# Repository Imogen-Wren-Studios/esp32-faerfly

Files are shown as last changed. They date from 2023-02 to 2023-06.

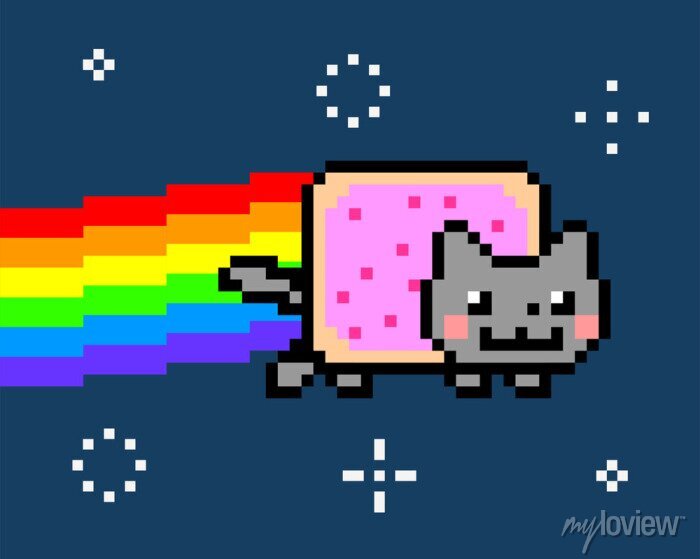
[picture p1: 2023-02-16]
image-sources/space-cat-creating-rainbo.jpg

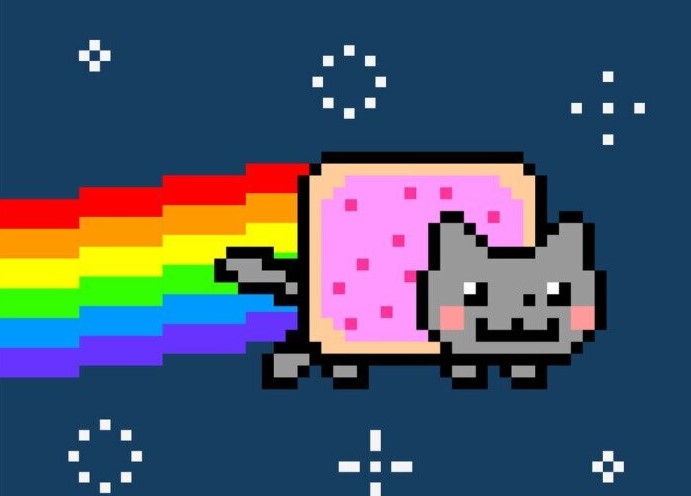
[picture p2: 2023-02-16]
image-sources/space-cat-creating-rainbow-crop.jpg

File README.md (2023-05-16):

#ESP32 FaerFly - Development Board
 Imogen Wren Business Card PCB
 





## Project Outline

_The project is a business card that can be handed out at gigs and work, and also a fun project to build!_

### Requirements
 1. A PCB business card I can hand out to people at gigs / work to advertise myself
 2. A fun electronics project or thing

### Idea

1. Mini pocket lightshow. Rechargable and interactive. Probably get it fabbed so it isnt a soldering project, but include a programming port so it can be reprogrammed easily. <br>
     **Advantages:**
    - Fun programming challenge - Can link to repo with working code in case of bricking
    - Card more likely to be used in the open and interacted with over time
    - Would have to be handed out with everything attached
    - Could exclude battery and make a point of indicating to reuse broken disposible vape for battery. Recycling electronic waste! 

 ## Strech Features
 
 - NFC Tap phone to link to linktree?
 - Edge connectors could be used as both touch interface, and connection to other hardware. Generic port? Is this now a new form we are trying to invent for development boards?
 - 3d printed case for different functions, like exposed touch pins, 

 ## Circuit Snippets
 
 ### WS2821b LED Implementation
 
  <br>
https://cdn-shop.adafruit.com/datasheets/WS2812B.pdf
- Vdd = 3.5 - 5.6 
- Vinput = VDD +-0.5

 Battery can be unregulated direct to LEDs & regulated to microcontroller
Slot for 2nd regulator for powering with 2s? or KISS

I think KISS

### Charging IC and LOw Voltage Cutoff

https://www.mouser.co.uk/ProductDetail/Littelfuse/SMAJ350A?

## Research

### AtTiny85 Interface
**DrAzzy - ATtiny Obsessee**
_Jan '20post #2_
_If you use my core (board manager url in sig), there is a serial bootloader (use the (optiboot) board def).
But you will still need an ISP programmer or arduino running Arduino as ISP sketch to bootload it (usbasps and nano clones are both 3 bucks or so on ebay/aliexpress, either is suitable).
You will also need a 0.1uf cap and 10k resistor for the autoreset circuit so the serial adapter can reset it into the bootloader. (Also, dont forget that you also need a 0.1uf ceramic cap between power and ground close to the t85 ti ensure reliable operation; without this the chip may behave erratically depending on circumstances - I mention this because it is very often omitted in designs I see here, particularly with tinies. You always need this for digital ICs unless otherwise specified in the datasheet. With the t85, if on breadboard or protoboard, i usually put this across the top of the chip to minimize the distance between cap and chip)_

#### USB - SPI Bridge

https://www.mouser.co.uk/ProductDetail/Microchip-Technology/MIC2550AYTS

#### USB C Connectors
https://www.mouser.co.uk/ProductDetail/Amphenol-Commercial-Products/124018402112A
https://www.lcsc.com/product-detail/span-style-background-color-ff0-USB-span-Connectors_G-Switch-GT-USB-7007A_C5299422.html

### LiPo Battery Charging
#### 1S
https://uk.rs-online.com/web/p/battery-management/7386360
https://www.mouser.co.uk/ProductDetail/Microchip-Technology-Atmel/MCP73832T-5ACI-OT
https://www.mouser.co.uk/datasheet/2/268/20001984g-846362.pdf

#### 2S
https://www.mouser.co.uk/ProductDetail/Microchip-Technology/MCP73844T-820I-MS

_This option needs regulator to 5v_

### Microcontroller Options
#### AtTiny85
- https://uk.farnell.com/microchip/attiny85-20su/mcu-8bit-attiny-20mhz-wsoic-8/dp/1455164
- Feels more "Haxxor" using a tiny processor
- More Difficult to implement
- The device achieves a throughput of 20 MIPS at 20 MHz and operates between 2.7 to 5.5V.
   - In voltage range 
- Have code almost ready to run https://github.com/Imogen-Wren-Studios/unicorn-attiny85

#### SAMD21
- 3.3v  MUST BE REGULATED
- Lots of experience with device
- https://www.mouser.co.uk/ProductDetail/Microchip-Technology/ATSAMD21E16L-AF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

#### AtMega382p
- Most commonly understood platform - better engagement
- https://www.lcsc.com/product-detail/Microcontroller-Units-MCUs-MPUs-SOCs_Microchip-Tech-ATMEGA328P-AU_C14877.html
- Expensive
- in stock ATM
- 1.8 - 5.5v - No Need for Regulator
  - Qty.	Unit Price	Ext. Price
  - 1+	US  $3.045
  - 10+	US  $2.7126 - 	US$ 27.13

### ESP32
- 3v3 Only - needs regulating
- Wifiability gives further haxxor abilities
- OTA Updates
https://www.lcsc.com/product-detail/WiFi-Modules_Espressif-Systems-ESP32-WROOM-32-N4_C82899.html
- Have some code that could be used: https://github.com/Imogen-Wren-Studios/esp32-ws2812b-glediator
- Price: 
  - 1+   -  	US$3.2455	
  - 10+	 -   US$2.9273

### Capaciative Sensing

https://www.instructables.com/Capacitive-Sensing-for-Dummies/
_Seems to mostly be used with a microcontroller, havnt managed to find an analog audio implementation yet_

https://docs.arduino.cc/built-in-examples/analog/Smoothing Smoothing Data from Capacative touch sensor

## Continued Development

Now the project has become more clearly defined, it is an ESP development board with built in WS2821b LEDs designed to be used as a wearable badge, or a light up stand
for 3D printing projects. It contains mounting tabs to assit in adding diffusers and optics. The wifi can be used to coordinate groups of them to sync colours around the room.

## Version 2 Development

After using version 1 for a little time, some clear places to improve have materialised.

1.  [] Replace GPIO surface pins with through holes
2.  [] Replace USB to serial with CP2102, CH340 is too flakey see [CP2102 USB to UART](https://blackcatsoftware.us/wp-content/uploads/2020/06/esp32-devkit-v1-schematic.pdf)
3.  [] Add BMP280 temp sensor
4.  [] Add Accellerometer
5.  [] Add digital microphone? - test theory before committing
6.  [] DMX interface? -> `The DMX output required the use of a MAX485 transceiver connected to the TX-pin of the ESP in order to produce DMX output.` `If you need to use another pin for output than the TX-pin, you'll need to change this in the ESP-Dmx library itself. This setting is located in src/dependencies/dmx/ESPDMX.cpp on line 31.`
7.  [x] Battery Positive to ADC1 (GPIO32-39) with 100k resistor for battery usermod
8.  [x] Change Battery Switch to switch between USB and battery (why didnt do this on version 1?!?!)
9.  [x] Check max charge current for BMS. Need at least 1A if possible 550mA max using 2k ohm shunt resistor

Does DMX make this project something it is not?

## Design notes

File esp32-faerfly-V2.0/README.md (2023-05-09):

# ESP32 - FaerFly - Version 2.0

## Changelog

- Added 100n cap from EN to GND for auto reset

## TODO

- Add Acellerometer
- Add BMP280 Sensors
- Change touch pins to holes, touch pins DID NOT work well

## Strech Goals

- Cut PCB size down to just the LEDs footprint - Use front and back of PCB

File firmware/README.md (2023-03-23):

# ESP32 FaerFly - Firmware README

## Concept and Initial Ideas

The brief is to design a light show, with wireless communication between devices to sync colours and patterns.

## Operational Modes
_More can be added as time goes on_

1. Known Starting Position into Randomness

Lightshow starts from a given frame, and then over time random elements are added. This will be easy to coordinate wirelessly, as the _leader_ simply has to 
transmit a starting point for the lightshow, then over t(time) the follower units can add their own random elements. This will look striking as elements will
seem to sync up then drift apart over time. The dataframe could contain the following information:

1. Colour 1*
2. Colour 2
3. Colour 3
4. Colour 4
5. Movement Pattern(s)
6. transition time (i.e. transition time set to 0 would update all followers instantly, wheres setting a transition of a few seconds to minuites would create the effect of the elements slowly drifting together and apart again.
7. brightness
8. time t to start introducing random elements
9. accelleration, how quickly to ramp up random elements

*Note colours could themselves be predefined pallets containing several colours

The advantage of this topology is all of these parameters can be coded into the leader for testing, and then would need just 1 dataframe between leader and followers to act.

## Development Map

1. Develop the single lightshow for the leader, using basic colours, movement and brightness
2. Introduce random elements over time
3. Change the speed of changes of random elements (accelleration)
4. introduce delay before adding random elements
5. Start development of wireless dataframe transmission
6. Start development of wireless dataframe reception
7. add additional animation elements, movements, fades & pulses
8. Add support for palettes as well as single colours.

- At this point this operational mode should be complete.

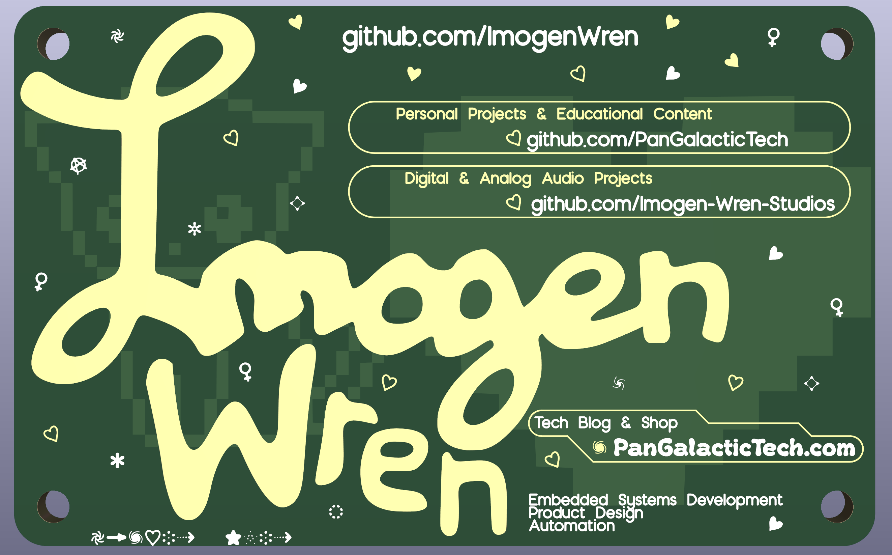
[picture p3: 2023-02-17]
Renders/Version 1 Render.png

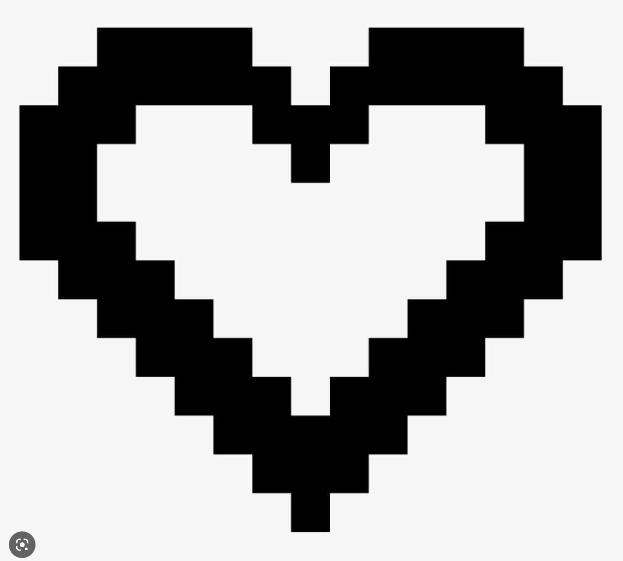
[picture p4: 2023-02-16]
image-sources/8-bit-heart-one.jpg

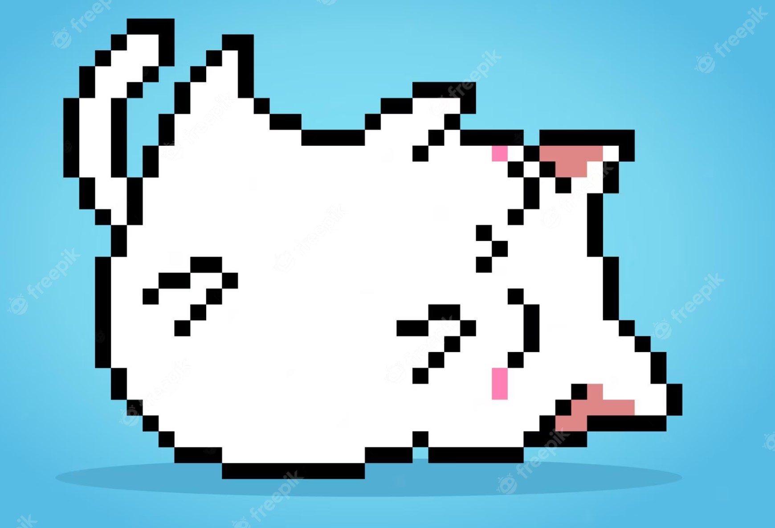
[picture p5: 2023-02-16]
image-sources/cat-rolling-back.jpg

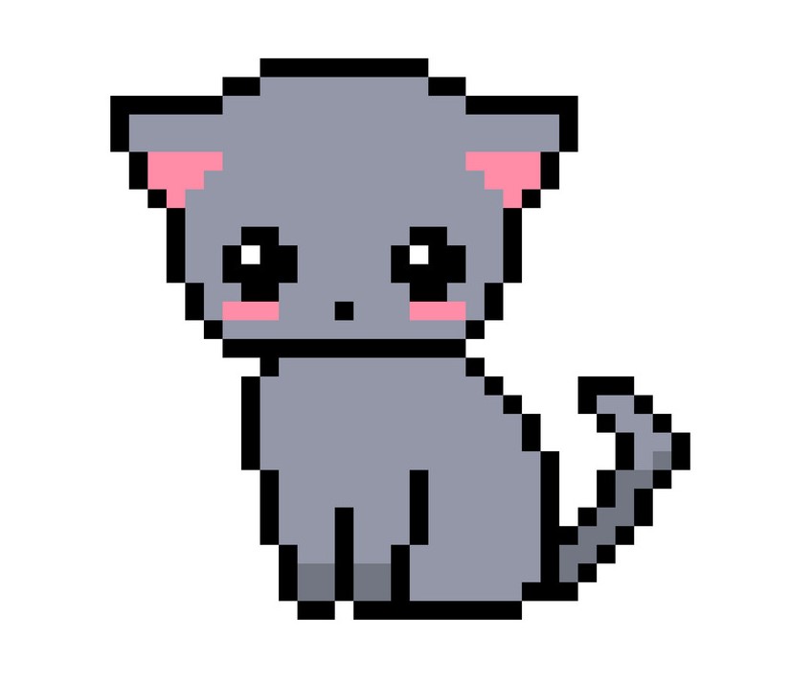
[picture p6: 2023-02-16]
image-sources/8-bit-pixel-gray-cat-cartoon-vector.jpg

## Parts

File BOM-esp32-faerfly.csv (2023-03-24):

# | Reference | Qty | Value | Footprint | DNP | JLCpart | Cost
1 | C1, C2, C3, C4, C5, C6, C7, C10, C13, C14, C15, C16, C17, C18, C19, C20, C21, C22, C23, C24 | 20 | 100n | 000_Capacitors_Immo:C_0805_2012_HandSolder_kawaii |  | C779975 | 0.02
2 | C8 | 1 | 10n | 000_Capacitors_Immo:C_0805_2012_HandSolder_kawaii |  | C83170 | 0.0051
3 | C9, C11 | 2 | 47p | 000_Capacitors_Immo:C_0805_2012_HandSolder_kawaii |  | C24659 | 0.0056
4 | C12 | 1 | 4n7 | 000_Capacitors_Immo:C_0805_2012_HandSolder_kawaii |  | C2915753 | 0.0118
5 | C25, C26 | 2 | 4u7 | Capacitor_Tantalum_SMD:CP_EIA-2012-12_Kemet-R_Pad1.30x1.05mm_HandSolder |  | C1954175 | 0.0994
6 | D1 | 1 | Blue | Diode_SMD:D_0805_2012Metric_Pad1.15x1.40mm_HandSolder |  | C84261 | 0.0158
7 | D2, D3 | 2 | BZV55B3V3 | Diode_SMD:D_MiniMELF |  | C268735 | 0.0221
8 | EC1 | 1 | 1000u | Capacitor_SMD:CP_Elec_10x10 |  | C134726 | 0.1866
9 | FB1 | 1 | FerriteBead | Inductor_SMD:L_0805_2012Metric_Pad1.05x1.20mm_HandSolder |  | C845115 | 0.558
10 | J8 | 1 | USB_C_Receptacle | Connector_USB:USB_C_Receptacle_Molex_105450-0101 |  | C134092 | 0.6619
12 | Q1, Q2 | 2 | BC817 | Package_TO_SOT_SMD:SOT-23 |  | C2137 | 0.0225
13 | R1, R2, R8, R9, R10, R11 | 6 | 10k | Resistor_SMD:R_0805_2012Metric_Pad1.20x1.40mm_HandSolder |  | C2930231 | 0.002
14 | R3, R12 | 2 | 4k7 | Resistor_SMD:R_0805_2012Metric_Pad1.20x1.40mm_HandSolder |  | C5140142 | 0.002
15 | R4, R5 | 2 | 27r | Resistor_SMD:R_0805_2012Metric_Pad1.20x1.40mm_HandSolder |  | C779975 | 0.002
16 | R6 | 1 | 470r | Resistor_SMD:R_0805_2012Metric_Pad1.20x1.40mm_HandSolder |  | C280020 | 0.0027
17 | R7 | 1 | 330r | Resistor_SMD:R_0805_2012Metric_Pad1.20x1.40mm_HandSolder |  | C3017834 | 0.0016
18 | R13, R14, R17 | 3 | 1k | Resistor_SMD:R_0805_2012Metric_Pad1.20x1.40mm_HandSolder |  | C218388 | 0.0082
19 | R15, R16 | 2 | 100r | Resistor_SMD:R_0805_2012Metric_Pad1.20x1.40mm_HandSolder |  | C217766 | 0.0093
20 | SW1 | 1 | SW_SPDT_small | 000_Switches_Immo:SW_SPDT_PCM12 |  | C221841 | 0.4487
21 | SW2 | 1 | BOOT | 000_Switches_Immo:SW_SPST_EVQPE1 |  | C699451 | 0.3052
22 | SW3 | 1 | EN | 000_Switches_Immo:SW_SPST_EVQPE1 |  | C699451 | 0.3052
23 | U1 | 1 | MCP73831-2-OT | Package_TO_SOT_SMD:SOT-23-5 |  | C424093 | 0.778
24 | U2 | 1 | AMS1117-3.3 | Package_TO_SOT_SMD:SOT-223-3_TabPin2 |  | C2992570 | 0.0488
25 | U3 | 1 | ESP32-WROOM-32 | RF_Module:ESP32-WROOM-32 |  | C473012 - C529577 | 3.5016
26 | U4 | 1 | CH340C | Package_SO:SOIC-16_3.9x9.9mm_P1.27mm |  | C84681 | 0.4725
27 | WLED1, WLED2, WLED3, WLED4, WLED5, WLED6, WLED7, WLED8, WLED9, WLED10, WLED11, WLED12 | 12 | WS2812B | LED_SMD:LED_WS2812B_PLCC4_5.0x5.0mm_P3.2mm |  | C2920042 | 0.0768

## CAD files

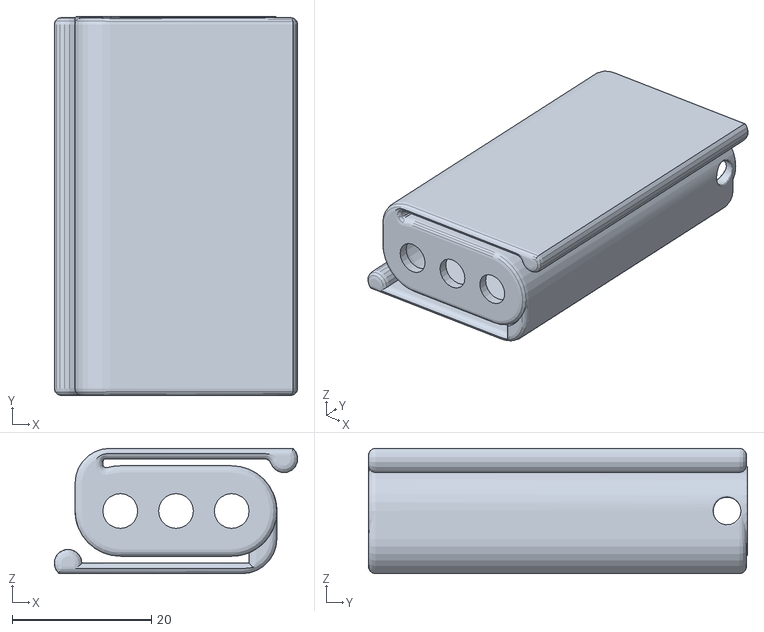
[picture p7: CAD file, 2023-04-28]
3D-cad/esp32-faerfly-inventor/case-stls/battery-holder/v2.0-B-battery-holder.stl
35.0 x 54.4 x 18.0

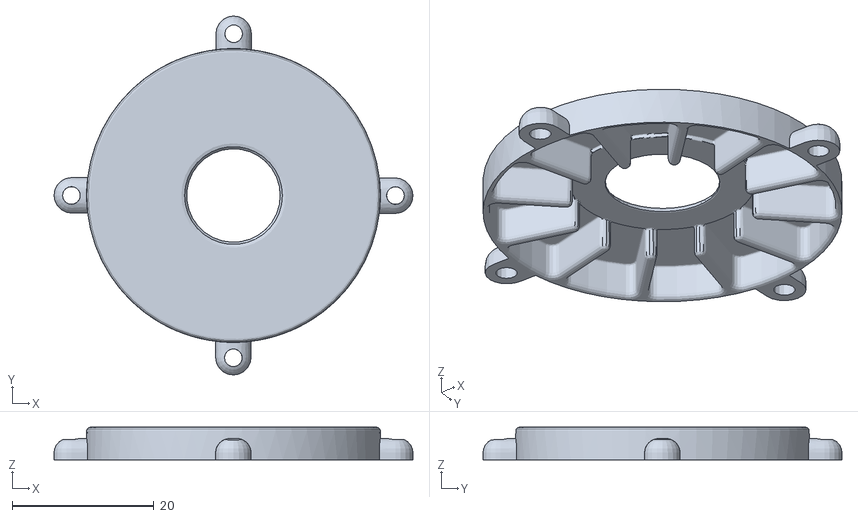
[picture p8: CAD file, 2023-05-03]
3D-cad/esp32-faerfly-inventor/case-stls/FINAL_VERSIONS/V3.0-diffuser_versionB.stl
50.6 x 50.6 x 4.60

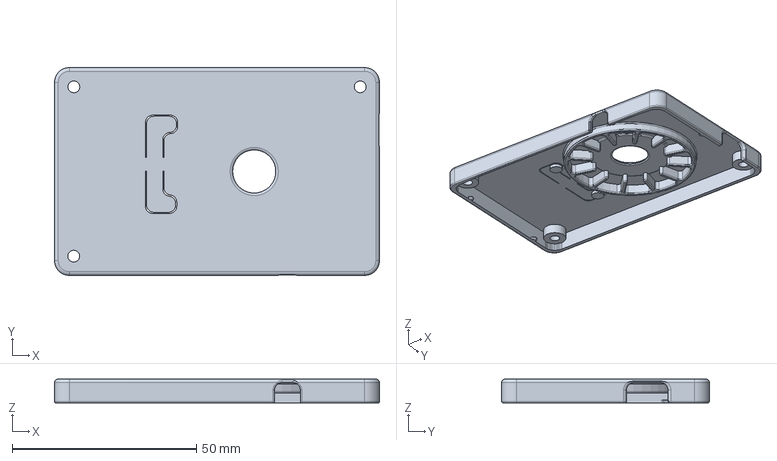
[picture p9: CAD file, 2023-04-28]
3D-cad/esp32-faerfly-inventor/case-topsideV1.3_A.stp
88.1 x 56.3 x 6.50 mm

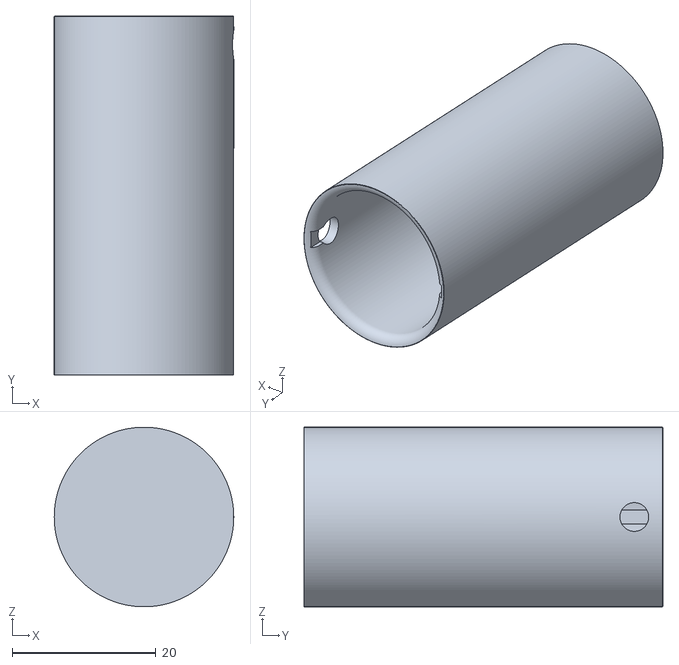
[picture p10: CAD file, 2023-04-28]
3D-cad/esp32-faerfly-inventor/case-stls/battery-holder/V1.0-battery-holder-A.stl
25.0 x 50.0 x 25.0

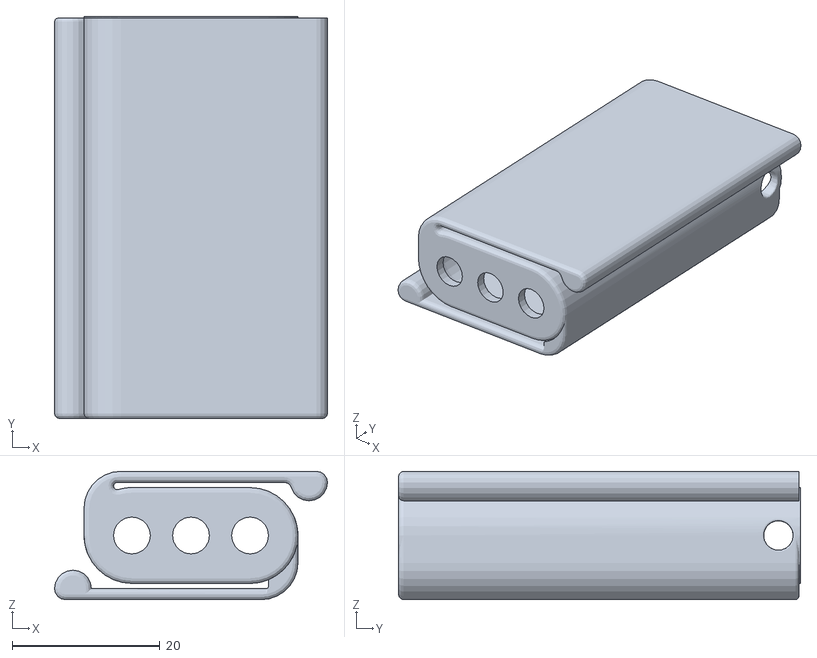
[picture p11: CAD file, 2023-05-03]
3D-cad/esp32-faerfly-inventor/case-stls/FINAL_VERSIONS/v2.0-B-battery-holder.stl
37.0 x 54.5 x 17.4

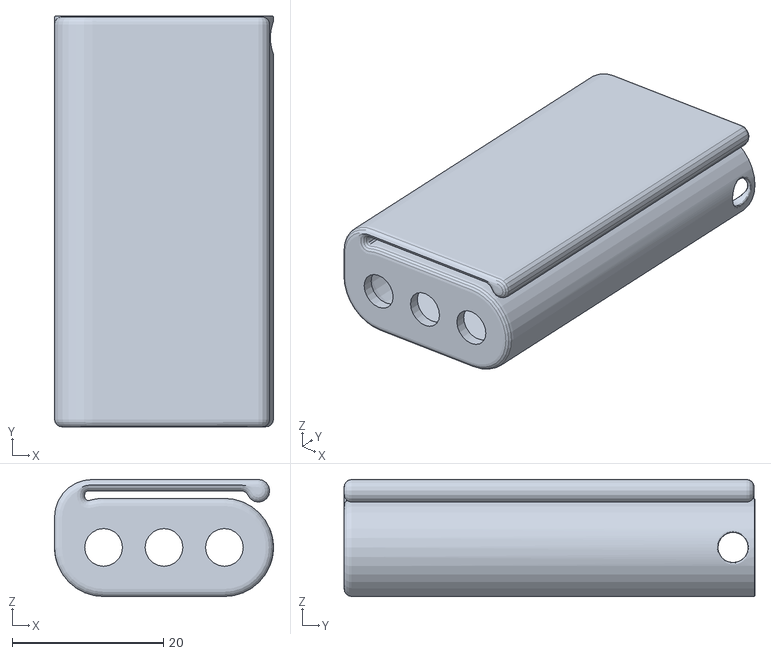
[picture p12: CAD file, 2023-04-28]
3D-cad/esp32-faerfly-inventor/case-stls/v1.2-B-battery-holder.stl
29.0 x 54.4 x 15.5

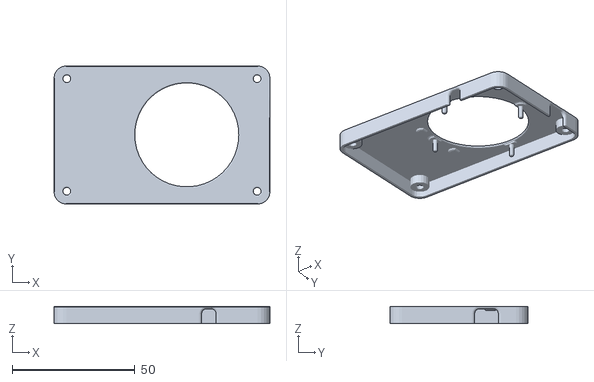
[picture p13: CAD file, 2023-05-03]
3D-cad/esp32-faerfly-inventor/case-stls/version-C/V2.0-case-outer-cover-VC.stl
88.1 x 56.3 x 7.00

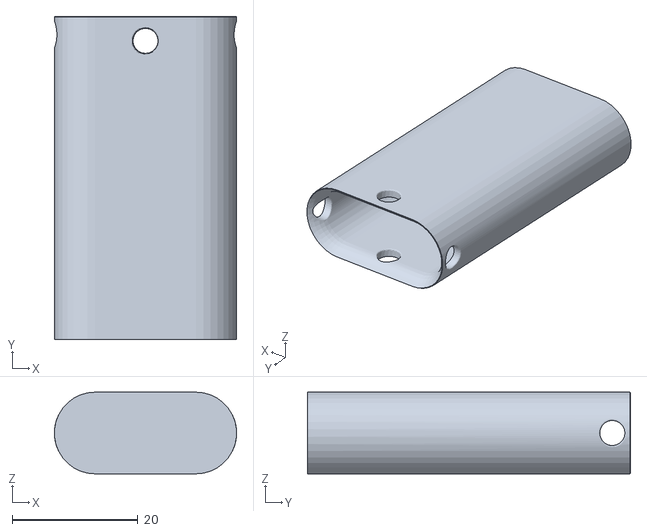
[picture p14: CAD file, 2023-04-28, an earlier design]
3D-cad/esp32-faerfly-inventor/case-stls/v1.0-B-battery-holder.stl
29.0 x 51.4 x 13.0

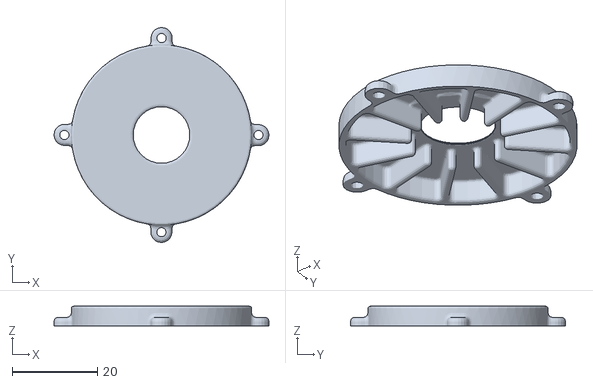
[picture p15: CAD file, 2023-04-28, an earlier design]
3D-cad/esp32-faerfly-inventor/case-stls/version-A/V2.2-diffuserl.stl
50.6 x 50.6 x 4.60

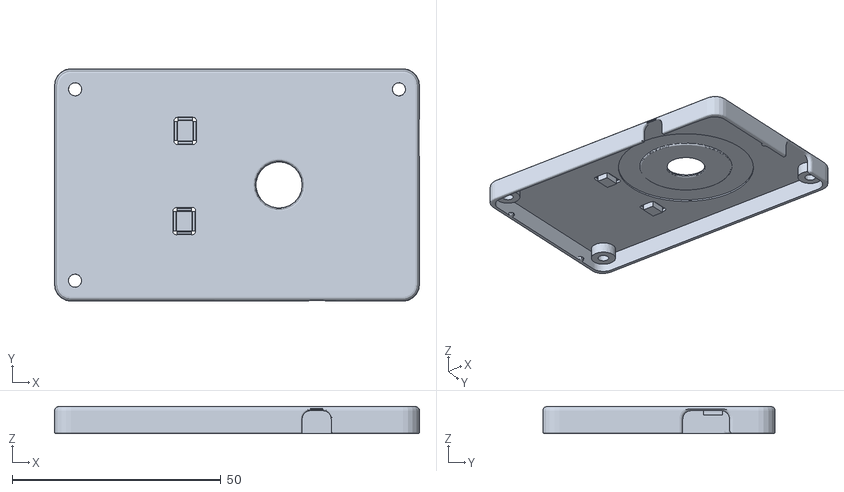
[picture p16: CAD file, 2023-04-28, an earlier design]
3D-cad/esp32-faerfly-inventor/case-stls/OLDER_VERSIONS/V1.2-B-faerfly-case-topside.stl
87.5 x 55.7 x 6.50

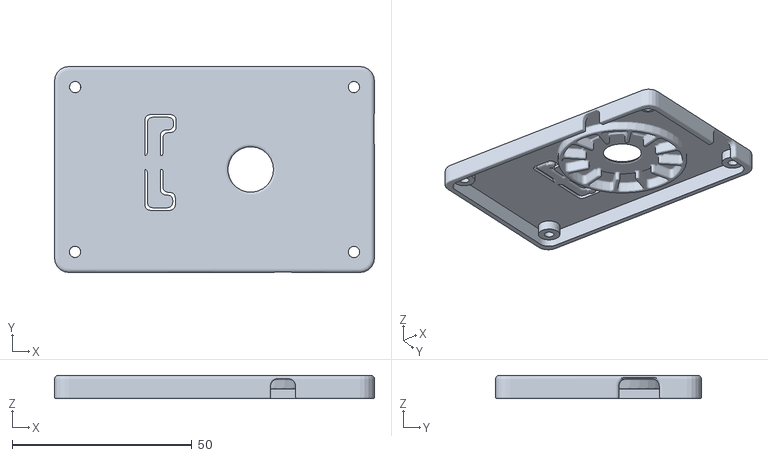
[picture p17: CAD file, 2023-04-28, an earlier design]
3D-cad/esp32-faerfly-inventor/case-stls/OLDER_VERSIONS/V1.6-case-topside-A.stl
89.1 x 57.3 x 6.50

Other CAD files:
3D-cad/esp32-faerfly-inventor/case-stls/version-C/V2.8-case-outer-cover-VC.dwg
3D-cad/esp32-faerfly-inventor/V1.3-case-topside-A.stp
3D-cad/esp32-faerfly-inventor/case-stls/FINAL_VERSIONS/V3.0-case-topside.stl
3D-cad/esp32-faerfly-inventor/case-stls/OLDER_VERSIONS/V1.3-case-topside-A.stl
3D-cad/esp32-faerfly-inventor/case-stls/version-B/V2.3-case-outer-cover-VB.stl
3D-cad/esp32-faerfly-inventor/case-stls/version-A/V2.2-outer-casestl.stl
3D-cad/esp32-faerfly-inventor/case-stls/FINAL_VERSIONS/V2.3-diffuser_versionB.stl
3D-cad/PCB.ipt
3D-cad/esp32-faerfly-inventor/OldVersions/V2.0-case-outer-cover-VB.0006.ipt
3D-cad/esp32-faerfly-inventor/OldVersions/case-topside-V2.0.0008.ipt
3D-cad/esp32-faerfly-inventor/OldVersions/case-topside.0021.ipt
3D-cad/esp32-faerfly-inventor/OldVersions/case-topside_v1.1.B.0001.ipt
3D-cad/esp32-faerfly-inventor/OldVersions/esp32-faerfly-case-V1.0.0005.iam
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

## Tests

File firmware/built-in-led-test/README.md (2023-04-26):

# ledObject *(V2.0.0)*
#### Built and maintained by [Imogen Wren](mailto:pangalactictech@gmail.com "Email me!") on behalf of [Pan Galactic Tech](https://PanGalacticTech.com)

## Features
* Object Orientated library for controling single LEDs.
* Seperate class defintions for "blink" (digital) and "fade" (PWM) LED outputs.
* Set up LED blink & fade behaviour without dealing with any delay() functions and the problems this causes.
* fadeLED inherets all functions from ledObject (blink) LEDs.
* Call blink or fade events which count down a specific number of ledEvents before ending.
* Set up blinks and fades that continue until stop method is called.
* Functions work with both AVR (ATmega) / Arduino Boards & ESP32/8266 Espressif Microcontrollers.
* Call as many constructors as needed, each one controls a single LED, but many can be stacked and accessed as object arrays.

___________________________________________________________________________________________________________

## Getting Started
### Deployment
1. Clone or Download library folder into Arduino IDE libraries folder.
2. Extract files from zipped folder if required.
3. Open Arduino IDE and select from example programs.

### Dependencies
No dependency for library function, however examples have the following dependencies:
* autoDelay_library available from [here](https://github.com/PanGalacticTech/autoDelay_Library) - written by PanGalacticTech
___________________________________________________________________________________________________________

## Use:

### Precompiler Requirements:

`#include <ledObject.h>   // Libary include N.B.This includes both ledObject & fadeLED classes ` <br> <br>

#### <u>AVR</u>
Define the LED pin and the initial state.

`#define LED_PIN 9                         // Define LED pin. If undefined - defaults to pin 13.` <br>
`#define INITIAL_STATE 1                  // Defines if LED pin starts with initial state ON or OFF - defaults to OFF` <br> <br>

#### <u>ESP32 / espressif</u>
For ESP32 & espressif boards, additional variables are required for setup.

`#define PWM_PIN 2                       // PWM drive capable pin`   <br>
`#define LED_CH  0                        // PWM Channel (ESP32 up to 16 channels total)`  <br>
`#define PWM_FREQ 5000                    // PWM Frequency (Hz)`    <br>
`#define PWM_RESO 8                       // PWM Resolution (bits)`   <br> <br>

___________________________________________________________________________________________________________

### Object Constructors

#### <u>AVR</u>
Declaring a blink LED object:

`ledObject led(LED_PIN) `<br> <br>

Declaring a fade LED object:

`fadeLED led(LED_PIN);      		// Note: LED_PIN must be PWM capable pin`<br> <br>

#### <u>ESP32 / espressif</u>
Declaring a fade LED object:

`fadeLED led(PWM_PIN, LED_CH, PWM_FREQ, PWM_RESO);      // ESP32 Requires 4 arguments for constructor`<br> <br>

<br>

___________________________________________________________________________________________________________

### Setup Functions:
Setup function for Blink LEDs pass the initial state as an argument. Defaults to off.

`led.begin(INITIAL_STATE);`<br> <br>

Setup function for Fade LEDs pass the initial brightness as an argument. Default is 150

`led.begin(INITIAL_BRIGHTNESS);`<br> <br>

<br>

___________________________________________________________________________________________________________

### Loop Functions:

Call performBlink() or PerformFade(); on LED objects to set the output pins.
This method should be called in main loop for each ledObject or fadeLED object. 

For blink objects <br>
`led.performBlink();`<br> <br>

For fade objects <br>
`led.performFade();`<br> <br>

Note: performBlink(); and performFade(); are both valid for fadeLED objects, performFade will also
carry out any Blink events triggered. Fading events take priority over Blink events if they are called together.

performFade(); is not valid for ledObjects. 

<br>

___________________________________________________________________________________________________________

### Starting & Stopping Events:
#### Starting Events

Blink & Fade events must be triggered to be performed.

Start a Blink event that continues indefinatly:

`led.startBlink(onDuration, offDuration);`<br> <br>

Call a Blink event that repeats a number of times:

`led.blinkEvent(numberofBlinks, onDuration, offDuration );`<br> <br>

Start a Fade event that continues indefinatly:

`led.startFading(minBrightness, maxBrightness , timeMs);  // timeMs is time for complete fade (Up & Down)`<br> <br>

Call a Fade event that repeats a number of times:

`led.fadeEvent(minimum , maximum, repeats, timeMs = 500);`<br> <br>

<br>
_____

#### Stopping Events

To stop a blink event call:

`led.stopBlink();`<br> <br>

To stop a fade event call:

`led.stopFading();`<br> <br>

___________________________________________________________________________________________________________

### Advanced Uses:
See [star_trek_flash_board](https://github.com/PanGalacticTech/ledObject_library/blob/master/star_trek_flash_board/star_trek_flash_board.ino) to see these techniques in action.

Set up arrays of ledObject and fadeLED constructors to iterate through large numbers of outputs easily. 

`ledObject flash[6] = {ledObject(2), ledObject(4), ledObject(7), ledObject(8), ledObject(12), ledObject(13)};`  <br> 
`                                      // Set up an array of ledObjects, each ledObject is passed an output pin`<br>

`fadeLED fade[6] = {fadeLED(3), fadeLED(5), fadeLED(6), fadeLED(9), fadeLED(10), fadeLED(11)};`<br>
`                                      // Set up an array of fadeLEDs. Each LED is passed a PWM capable output pin`<br> <br>

Iterate through object array using a for loop for setup functions.

`for (int i = 0; i < NUM_FLASHERS; i++) {`<br>
`    flash[i].begin(INITIAL_STATE);`<br>
` }`<br> <br>

Iterate through object array using a for loop to start or change flashing/fading behaviour.

`for (int i = 0; i < NUM_FADERS; i++) {`<br>
`    fade[i].startFading(0, 255, random(1, 1000));                    // feed new random numbers into the fade objects`<br>
`  }`<br> <br>

Iterate through object array with perform function (Must be called in every loop).

`for (int i = 0; i < NUM_FADERS; i++) {`<br>
`   fade[i].performFades();        // PerformFade events, also performs blink events.`<br>
` }` <br> <br>

<br>
<br>

___________________________________________________________________________________________________________
___________________________________________________________________________________________________________

### Limitations:

<br>

### Known Issues V2.0.0
  - Please report any bugs or issues found.
  - 
### Known Issues V1.0.0
  - Please report any bugs or issues found.

<br>

### Features to be Added 

<br>
<br>

## About
### Built With
* [Arduino IDE](https://www.arduino.cc/) - Default IDE

### Author
#### Imogen Wren
* [LinkedIn](https://www.linkedin.com/in/declan-heard-91103b58/)
* Email: [Personal](mailto:Imogen.Wren91@gmail.com "Imogen.Wren91@gmail.com") | [Company](mailto:PanGalacticTech@gmail.com "PanGalacticTech@gmail.com")
* [Github Profile](https://github.com/PanGalacticTech)

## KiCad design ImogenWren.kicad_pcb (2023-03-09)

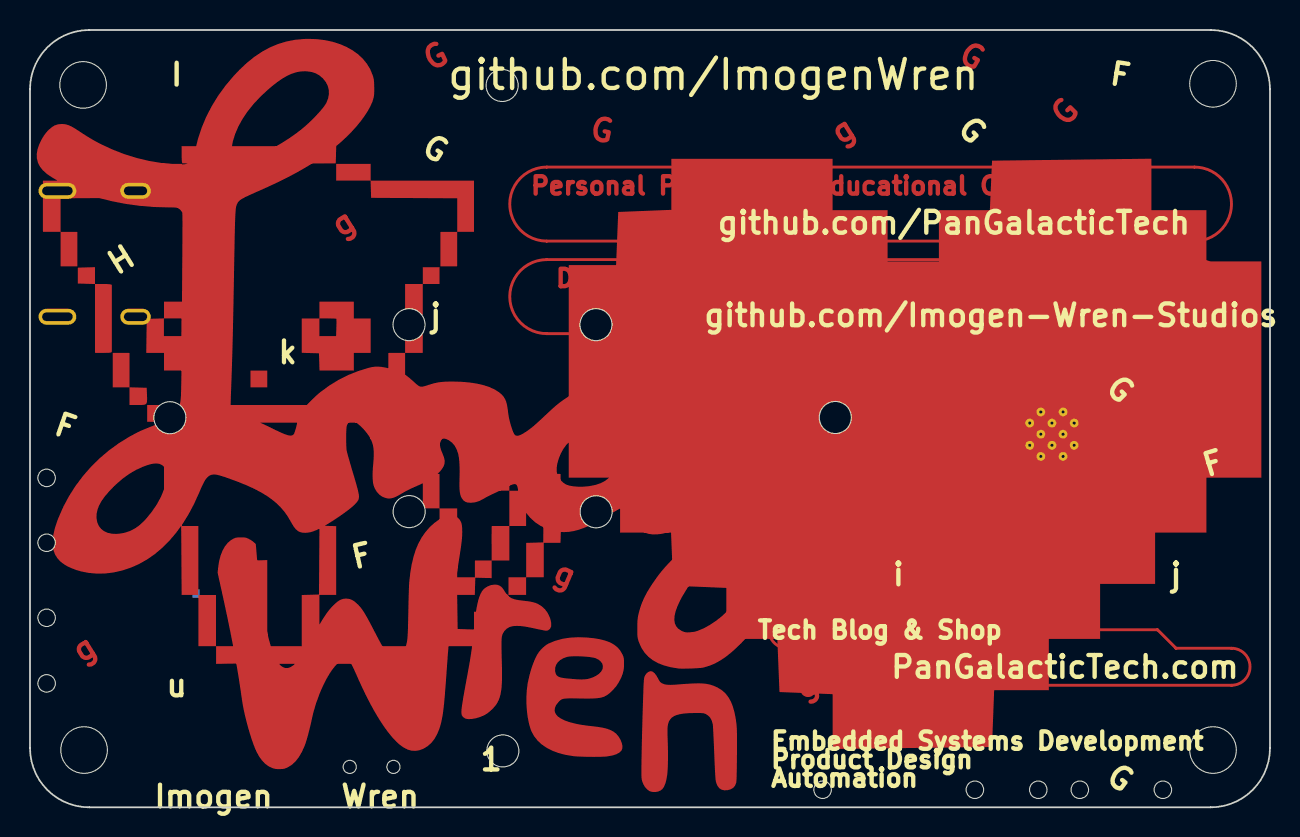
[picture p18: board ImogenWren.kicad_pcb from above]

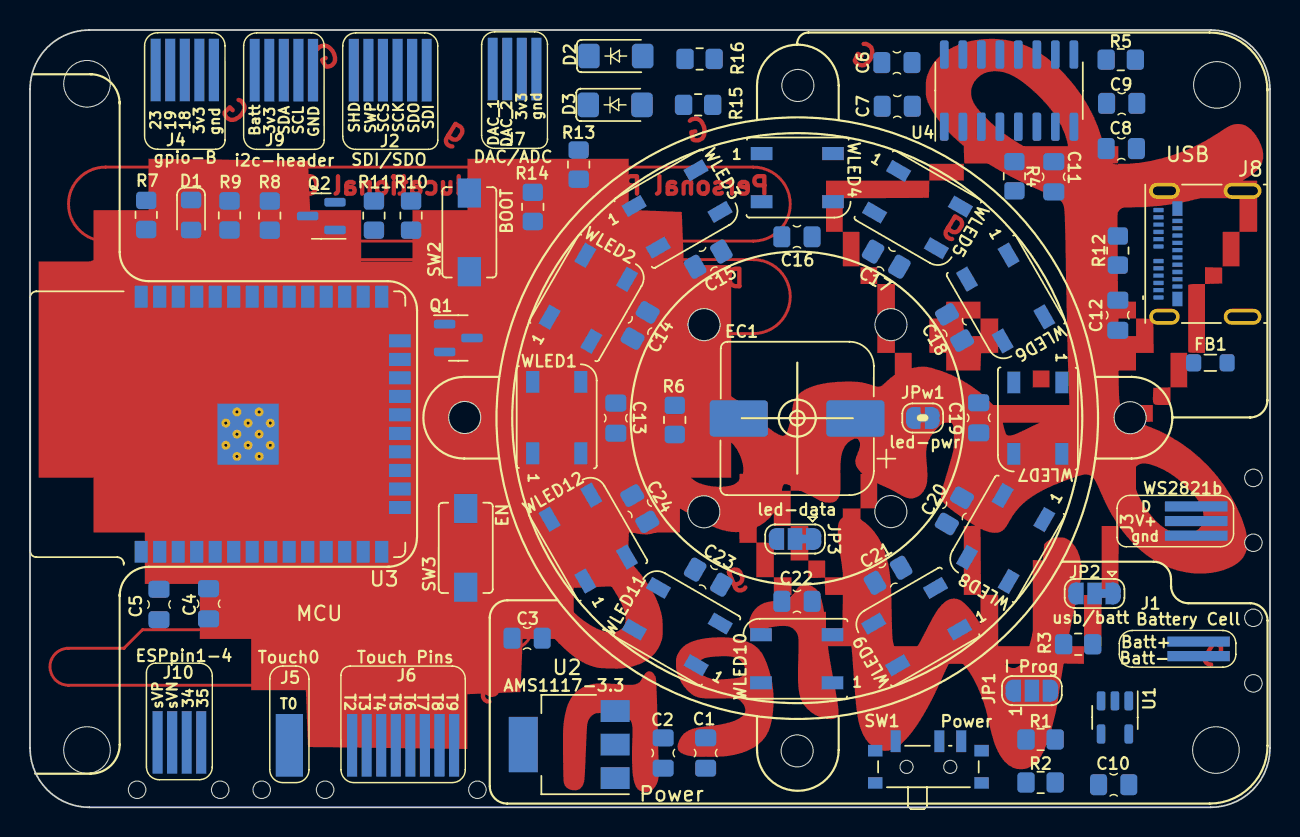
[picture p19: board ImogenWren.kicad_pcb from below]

Board: 2 copper layers, 85.1 x 53.3 mm, 80 parts (80 on the bottom side), 73 nets, no tracks yet.

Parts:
C1, C2, C3, C4, C5, C6, C7, C10, C13, C14, C15, C16, C17, C18, C19, C20, C21, C22, C23, C24: 100n; C_0805_2012_HandSolder_kawaii
C8: 10n; C_0805_2012_HandSolder_kawaii
C9, C11: 47p; C_0805_2012_HandSolder_kawaii
C12: 4n7; C_0805_2012_HandSolder_kawaii
D1: Blue; LED_0805_2012_Kawaii
D2, D3: BZV55B3V3; D_MiniMELF_kawaii
EC1: 1000u; CP_Elec_10x10_kawaii
FB1: FerriteBead; L_0805_2012Metric_Pad1.05x1.20mm_HandSolder
J1: Battery Cell; 2-pin-edge
J2: SDI/SDO; 6-pin-edge-touch
J3: WS2821b; 3-pin-edge
J4: gpio-B; 5-pin-edge-touch
J5: Touch0; 1-pin-edge-touch-xl
J6: Touch Pins; 8-pin-edge-touch
J7: DAC/ADC; 4-pin-edge
J8: USB_C_Receptacle; USB_C_Receptacle_Molex_105450-0101
J9: i2c-header; 5-pin-edge-touch
J10: ESPpin1-4; 4-pin-edge
JP1: I Prog; SolderJumper-3_P1.3mm_Open_RoundedPad1.0x1.5mm_NumberLabels
JP2: usb/batt; SolderJumper-3_P1.3mm_Bridged12_RoundedPad1.0x1.5mm
JP3: led-data; SolderJumper-3_P1.3mm_Bridged12_RoundedPad1.0x1.5mm
JPw1: led-pwr; SolderJumper-2_P1.3mm_Bridged_RoundedPad1.0x1.5mm
Q1, Q2: BC817; SOT-23
R1, R2, R8, R9, R10, R11: 10k; R_0805_2012Metric_Pad1.20x1.40mm_HandSolder
R3: 4k7; R_0805_2012Metric_Pad1.20x1.40mm_HandSolder
R4, R5: 27r; R_0805_2012Metric_Pad1.20x1.40mm_HandSolder
R6: 470r; R_0805_2012Metric_Pad1.20x1.40mm_HandSolder
R7: 330r; R_0805_2012Metric_Pad1.20x1.40mm_HandSolder
R12: 5k2; R_0805_2012Metric_Pad1.20x1.40mm_HandSolder
R13, R14: 220r; R_0805_2012Metric_Pad1.20x1.40mm_HandSolder
R15, R16: 100r; R_0805_2012Metric_Pad1.20x1.40mm_HandSolder
SW1: SW_SPDT_small; SW_SPDT_PCM12
SW2: BOOT; SW_SPST_EVQPE1
SW3: EN; SW_SPST_EVQPE1
U1: MCP73831-2-OT; SOT-23-5
U2: AMS1117-3.3; SOT-223-3_TabPin2
U3: ESP32-WROOM-32; ESP32-WROOM-32_KAWAII
U4: CH340C; SOIC-16_3.9x9.9mm_P1.27mm
WLED1, WLED2, WLED3, WLED4, WLED5, WLED6, WLED7, WLED8, WLED9, WLED10, WLED11, WLED12: WS2812B; LED_WS2812B_PLCC4_5.0x5.0mm_P3.2mm

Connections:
18: J4.A3, U3.30 (GPIO18)
19: J4.A4, U3.31 (GPIO19)
23: D1.2 (A), J4.A5, U3.37 (GPIO23)
/BATTERY_POWER: JP2.1 (A), SW1.1 (A), U1.3 (V_{BAT})
/BATTERY_POWER_BUS: C1.1, C2.1, EC1.1, J3.A2, J9.A5, JP2.2 (C), JPw1.1 (A), U2.3 (VI)
/CHARGE_INHIBIT: R1.1, R2.1, R3.1, U1.5 (PROG)
/ESP32/3V3_BUS: C3.1, C5.1, J4.A2, J7.A2, J9.A4, R8.1, R9.1, U2.2 (VO), U3.2 (VDD)
/ESP32/D+: R5.1, U4.5 (UD+)
/ESP32/D-: R4.1, U4.6 (UD-)
/ESP32/LED_DATA_OUT: R6.2, U3.29 (GPIO5)
/ESP32/MCU_5V_BUS: C6.1, U4.16 (VCC)
/ESP32/USB ESP32 CH340 Interface /ESP_EN: C4.1, Q2.3 (C), SW3.1, U3.3 (EN)
/ESP32/USB ESP32 CH340 Interface /ESP_IO0: Q1.3 (C), SW2.1, U3.25 (IO0/GPIO0/T1)
/ESP32/USB ESP32 CH340 Interface /RxD_B: U3.35 (TXD0/GPIO1), U4.3 (RXD)
/ESP32/USB ESP32 CH340 Interface /TxD_B: U3.34 (RXD0/GPIO3), U4.2 (TXD)
/USB/D+: C9.1, J8.A6 (D+), J8.B6 (D+), R5.2
/USB/D-: C11.1, J8.A7 (D-), J8.B7 (D-), R4.2
/USB_POWER: C10.1, C12.1, FB1.2, JP2.3 (B), U1.4 (V_{DD})
/WS2812b LEDs/5V_IN: C13.1, C14.1, C15.1, C16.1, C17.1, C18.1, C19.1, C20.1, C21.1, C22.1, C23.1, C24.1, JPw1.2 (B), WLED1.1 (VDD), WLED2.1 (VDD), WLED3.1 (VDD), WLED4.1 (VDD), WLED5.1 (VDD), WLED6.1 (VDD), WLED7.1 (VDD), WLED8.1 (VDD), WLED9.1 (VDD), WLED10.1 (VDD), WLED11.1 (VDD), WLED12.1 (VDD)
/WS2812b LEDs/DATA_IN: JP3.1 (A), R6.1, WLED1.4 (DIN)
/WS2812b LEDs/DATA_OUT: JP3.3 (B), WLED12.2 (DOUT)
GND: C1.2, C2.2, C3.2, C4.2, C5.2, C6.2, C7.2, C13.2, C14.2, C15.2, C16.2, C17.2, C18.2, C19.2, C20.2, C21.2, C22.2, C23.2, C24.2, EC1.2, J3.A1, J4.A1, J7.A1, J9.A1, R7.2, R15.1, R16.1, SW2.2, SW3.2, U2.1 (GND), U3.1 (GND), U3.15 (GND), U3.38 (GND), U3.39 (GND), U4.1 (GND), WLED1.3 (VSS), WLED2.3 (VSS), WLED3.3 (VSS), WLED4.3 (VSS), WLED5.3 (VSS), WLED6.3 (VSS), WLED7.3 (VSS), WLED8.3 (VSS), WLED9.3 (VSS), WLED10.3 (VSS), WLED11.3 (VSS), WLED12.3 (VSS)
GNDPWR: C8.2, C9.2, C10.2, C11.2, C12.2, J1.A1, J8.A1 (GND), J8.A12 (GND), J8.B1 (GND), J8.B12 (GND), J8.S1 (SHIELD), JP1.2 (C), R1.2, R12.1, U1.2 (V_{SS})
unnamed: C8.1, FB1.1, J8.A4 (VBUS), J8.A9 (VBUS), J8.B4 (VBUS), J8.B9 (VBUS)
unnamed: D1.1 (K), R7.1
unnamed: D2.2 (A), R16.2
unnamed: D2.1 (K), J7.A3, R14.1
unnamed: D3.2 (A), R15.2
unnamed: D3.1 (K), J7.A4, R13.1
unnamed: J8.A5 (CC1), R12.2
unnamed: JP1.1 (A), R2.2
unnamed: JP1.3 (B), R3.2
unnamed: J3.A3, JP3.2 (C)
unnamed: Q1.1 (B), R10.2
unnamed: Q1.2 (E), R11.1, U4.13 (~DTR)
unnamed: Q2.1 (B), R11.2
unnamed: Q2.2 (E), R10.1, U4.14 (~RTS)
unnamed: J1.A2, SW1.2 (B)
unnamed: J6.A1, U3.24 (GPIO2(T2))
unnamed: J5.A1, U3.26 (GPIO4(T0))
unnamed: J6.A4, U3.14 (GPIO12(T5))
unnamed: J6.A3, U3.16 (GPIO13(T4))
unnamed: J6.A5, U3.13 (GPIO14(T6))
unnamed: J6.A2, U3.23 (GPIO15(T3))
unnamed: R13.2, U3.10 (GPIO25(DAC_1))
unnamed: R14.2, U3.11 (GPIO26(DAC_2))
unnamed: J6.A6, U3.12 (GPIO27(T7))
unnamed: J6.A8, U3.8 (GPIO32(T9))
unnamed: J6.A7, U3.9 (GPIO33(T8))
unnamed: J10.A3, U3.6 (IO34)
unnamed: J10.A4, U3.7 (IO35)
unnamed: J2.A3, U3.20 (SCK/CLK)
unnamed: J2.A4, U3.19 (SCS/CMD)
unnamed: J2.A1, U3.22 (SDI/SD1)
unnamed: J2.A2, U3.21 (SDO/SD0)
unnamed: J10.A2, U3.5 (SENSOR_VN)
unnamed: J10.A1, U3.4 (SENSOR_VP)
unnamed: J2.A6, U3.17 (SHD/SD2)
unnamed: J2.A5, U3.18 (SWP/SD3)
unnamed: C7.1, U4.4 (V3)
unnamed: WLED1.2 (DOUT), WLED2.4 (DIN)
unnamed: WLED2.2 (DOUT), WLED3.4 (DIN)
unnamed: WLED3.2 (DOUT), WLED4.4 (DIN)
unnamed: WLED4.2 (DOUT), WLED5.4 (DIN)
unnamed: WLED5.2 (DOUT), WLED6.4 (DIN)
unnamed: WLED6.2 (DOUT), WLED7.4 (DIN)
unnamed: WLED7.2 (DOUT), WLED8.4 (DIN)
unnamed: WLED8.2 (DOUT), WLED9.4 (DIN)
unnamed: WLED9.2 (DOUT), WLED10.4 (DIN)
unnamed: WLED10.2 (DOUT), WLED11.4 (DIN)
unnamed: WLED11.2 (DOUT), WLED12.4 (DIN)
SCL: J9.A2, R8.2, U3.36 (GPIO22)
SDA: J9.A3, R9.2, U3.33 (GPIO21)

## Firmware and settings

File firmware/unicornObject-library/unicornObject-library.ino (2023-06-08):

/* unicornObject Library Example

    Imogen Wren
    30/04/2023

    unicornObject is an attempt to further abstract and simplify lighting shows using the FastLED library

    The Targest is a basic API that can be accessed to trigger a range of different animation types

    There are 3 different factors that affect animations in this library.
    1. The currentPalette, nextPalette and blend speed
        - Affects which colour palettes are used to pick individual hues from
        - Controls how quickly colours swap between palettes
    2. The Local Steps and Global Steps variables, along with refresh speed.
        - Local Steps
          - Controlls how many individual colours from the palette of 255 we can see at any one time
        - Global Steps
          - Controls how quickly the effect moves around the whole palette spectrum
    3. the update/FillBuffer algorithms
        - affects how the palettes are applied to the LEDs


*/

/*
// FastLED definitions MUST come before #include "unicornObject.h"
#define LED_PIN 5
#define NUM_LEDS 12

#define LED_TYPE WS2811
#define COLOR_ORDER GRB

#define UPDATES_PER_SECOND 30
#define HUE_STEPS 1  // Number of steps to advance through palette between each for loop. Origionally 3

#define ANIMATION_BLEND_SPEED 128
#define NORMAL_BLEND_SPEED 2
*/

#include "unicornObject.h"




//#define START_PALETTE RainbowColors_p  // Sterile while palette to start with

using namespace pridePalettes;

#define START_PALETTE pridePalettes::lesbian
#define SECOND_PALETTE pridePalettes::lesbian


#include <autoDelay.h>

autoDelay paletteDelay;      // delay for swapping palettes
autoDelay speedChangeDelay;  // delay for changing framerate and animation speed  NOT USED AT THE MOMENT
autoDelay globalStepsDelay;  // delay for changing number of global steps
autoDelay effectDelay;
autoDelay directionDelay;
autoDelay triggerAnimation;

  unicornObject unicorn;


#define BRIGHTNESS 70
#define HUE_INIT 0
#define SAT_INIT 255
#define VAL_INIT BRIGHTNESS


CRGBPalette16 prideArray[11] = {
  pridePalettes::pride,
  pridePalettes::lesbian,
  pridePalettes::gay,
  pridePalettes::bisexual,
  pridePalettes::enby,
  pridePalettes::trans,
  pridePalettes::ace,
  pridePalettes::aero,
  pridePalettes::inter,
  pridePalettes::demi,
  pridePalettes::queer
};


char prideNames[][11] = {
  "pride",
  "lesbian",
  "gay",
  "bisexual",
  "enby",
  "trans",
  "ace",
  "aero",
  "inter",
  "demi",
  "queer"
};



void setup() {
  Serial.begin(115200);
  unicorn.begin();
  unicorn.currentPalette = START_PALETTE;
  unicorn.nextPalette = SECOND_PALETTE;
  unicorn.setBrightness(BRIGHTNESS);
  unicorn.introAnimation(BRIGHTNESS);
  unicorn.setBlendSpeed(255);
  unicorn.setEffect(unicorn.chase);
  unicorn.setDirection(true);
  unicorn.setFrameRate(30);
}

#define CHANGE_PALETTE_S 40
#define CHANGE_STEPS random(5, 20)  // this should be random for best effect
int8_t change_steps_delay = 20;
int8_t effects_change_delay = 20;  // going to be set for 20 seconds
int8_t direction_change_delay = 10;
int8_t trigger_drops_delay = 2;

int8_t lastSteps = 1;  // if the last step was 3 or -3 make it reset to 1

#define RANDOMISE_EFFECT true
#define RANDOMISE_STEPS true
#define RANDOMISE_DIRECTION true
#define RANDOMISE_PALETTE true

void loop() {
  //unicorn.paintRGB(250, 250, 250);   //// Solid Color Wash


  if (triggerAnimation.secondsDelay(trigger_drops_delay)) {
    unicorn.animateCycle = 0;
  }

  // Changing the effect
  if (RANDOMISE_EFFECT) {
    if (effectDelay.secondsDelay(effects_change_delay)) {
      Serial.print("Changing Effect to: ");
      int newEffect = random(4);
      Serial.println(newEffect);
      switch (newEffect) {
        case 0:
          unicorn.setEffect(unicorn.smooth);  // god this is clunky, can we hide the array call inside the method?
          break;
        case 1:
          unicorn.setEffect(unicorn.chase);
          break;
        case 2:
          unicorn.setEffect(unicorn.spread);
          break;
        case 3:
          unicorn.setEffect(unicorn.drop);
          break;
        default:
          unicorn.setEffect(unicorn.smooth);  // god this is clunky, can we hide the array call inside the method?
          break;
      }
    }
  }


  if (RANDOMISE_DIRECTION) {
    if (directionDelay.secondsDelay(direction_change_delay)) {  // This still only works on chase NOT on smooth GAAH #TODO work out how this can actually work for smooth
      Serial.print("Changing Direction: ");
      bool newDirection;
      if (unicorn.ledDirection) {
        newDirection = false;
      } else {
        newDirection = true;
      }
      Serial.println(newDirection);
      unicorn.setDirection(newDirection);
      direction_change_delay = random(23);
      Serial.print("New Direction Delay: ");
      Serial.println(direction_change_delay);
    }
  }


  if (RANDOMISE_STEPS) {
    // Changing the color steps
    // steps_delay controlls the speed of the animations. They are controlled to not go too fast, or at least if they go fast to turn back to slow quickly
    if (globalStepsDelay.secondsDelay(change_steps_delay)) {
      int8_t newStepVal = random(-4, 4);
      change_steps_delay = random(5, 30);
      if (lastSteps > 1 || lastSteps < -1) {  // force it into slower animations more frequently // this is junk but written quickly
        newStepVal = 1;
      }
      if (newStepVal > 2 || newStepVal < -2) {
        change_steps_delay = random(1, 4);
      }
      if (newStepVal == 0) {
        change_steps_delay = random(1, 2);
      }
      Serial.print("  New seconds delay: ");
      Serial.print(change_steps_delay);
      Serial.print("  newGlobalStepVal : ");
      Serial.print(newStepVal);
      unicorn.setGlobalSteps(newStepVal);  // Why was this commented out!?! sheet

      //LocalStep controlls the percentage of the entire palette we see at one time. if there are 256 positions, and 12 LEDs, then by selecting values close to +-20-22 then we will see all the colours at the same time.
      // Smaller numbers will show a smaller proportion of the colours, and larger numbers will give a "patchwork" look as further away indexes will be between close by indexes.
      int8_t newLocalStep = random(-22, 22);
      Serial.print("  newLocalStep: ");
      Serial.println(newLocalStep);
      unicorn.setLocalSteps(newLocalStep);
      lastSteps = newStepVal;
    }
  }

  if (RANDOMISE_PALETTE) {
    // Changing Palettes
    if (paletteDelay.secondsDelay(CHANGE_PALETTE_S)) {
      Serial.print("Changing Palette to: ");
      Serial.println();
      uint8_t palettePicker = random(0, 13);
      if (palettePicker == 13 || palettePicker == 11) {
        Serial.println("Random Saturated Palette");
        unicorn.setNextPalette(unicorn.makeRandomSaturatedPallet());
      } else if (palettePicker == 12) {
        Serial.println("Random Pastel Palette");
        unicorn.setNextPalette(unicorn.makeRandomPastelPallet());
      } else {
        Serial.print("Pride Palette: ");
        Serial.print(palettePicker);
        unicorn.setNextPalette(prideArray[palettePicker]);
        Serial.print(" ");
        Serial.println(prideNames[palettePicker]);
      }
      unicorn.setLocalSteps(21);  // 21 should give entire palette   // Could also change localStep here so we get a preview of the new palette
      if (unicorn.currentEffect == unicorn.smooth) {
        unicorn.setGlobalSteps(1);  // This means both effects types should work
      } else {
        unicorn.setGlobalSteps(20);
      }

      change_steps_delay = 20;  // 4 second preview of new palette?                                        // Make blending really quick so it previews the next colours, the slow mixing of colours is kinda done for this gotta be quicker.
    }
  }

  //#TODO FEATURES TO ADD
  // circle light effect
  // -- Pallette is applied by:
  // -- Picking a random LED, then applying palette to LEDS either side untill they meet back in the middle
  // -- Needs some way of turning the LED dark again after, or fading in and out
  // Corrupt algorithm

  // Streching Goals
  // Sorting Algorithm
  // - palette is applied as a bunch of random colours, then over time it sorts things into the correct groupings




  unicorn.update();
}

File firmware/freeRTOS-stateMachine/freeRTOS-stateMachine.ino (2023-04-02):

/* Free RTOS with OTA Support

   https://arduino.stackexchange.com/questions/77004/esp32-is-ota-compatible-with-freertos

*/



#if CONFIG_FREERTOS_UNICORE
#define ARDUINO_RUNNING_CORE 0
#else
#define ARDUINO_RUNNING_CORE 1
#endif

#ifndef LED_BUILTIN
#define LED_BUILTIN 2
#endif


#define ESP32_RTOS  // Uncomment this line if you want to use the code with freertos only on the ESP32
// Has to be done before including "OTA.h"

#include "OTA.h"
#include "credentials.h"

#include <autoDelay.h>


#define UPDATES_PER_SECOND 30
#define HUE_STEPS 5  // Number of steps to advance through palette between each for loop. Origionally 3

autoDelay autoDelay;


// Fast LED
#include <FastLED.h>
#define LED_PIN 5
#define NUM_LEDS 8
#define BRIGHTNESS 255
#define LED_TYPE WS2811
#define COLOR_ORDER GRB
CRGBArray<NUM_LEDS> leds;
uint8_t updates_per_second = 30;

#include "globals.h"
#include "pride_palettes.h"



// Define state machine task
void TaskStateMachine(void *pvParameters);
// Define task for the WS2821b controller
void TaskLEDcontrol(void *pvParameters);

// define two tasks for Blink & AnalogRead
void TaskBlink(void *pvParameters);
void TaskAnalogReadA3(void *pvParameters);

TaskHandle_t xBlinkHandle;  // Handler for task is passed as argument to task. Only needed for task control if required
TaskHandle_t xLEDHandle;
TaskHandle_t xSensorHandle;

// the setup function runs once when you press reset or power the board
void setup() {

  // initialize serial communication at 115200 bits per second:
  Serial.begin(115200);
  Serial.println("-ESP32-FreeRTOS- Booting");
  setupOTA("ESP32 - FaerFly", ssid, password);

  fastled_setup();

  // Now set up two tasks to run independently.
  xTaskCreatePinnedToCore(
    TaskStateMachine, "StateMachineTask", 2048, NULL, 1  // Priority
    ,
    NULL  // State machine should always be active
    ,
    ARDUINO_RUNNING_CORE);


  xTaskCreatePinnedToCore(
    TaskLEDcontrol, "LEDcontrol",
    1024  // Stack size
    ,
    NULL,
    1  // Priority
    ,
    &xLEDHandle,
    ARDUINO_RUNNING_CORE);

  xTaskCreatePinnedToCore(
    TaskBlink, "TaskBlink"  // A name just for humans
    ,
    1024  // This stack size can be checked & adjusted by reading the Stack Highwater
    ,
    NULL, 2  // Priority, with 3 (configMAX_PRIORITIES - 1) being the highest, and 0 being the lowest.
    ,
    &xBlinkHandle  // &xHandle // Set to NULL if handler not required
    ,
    ARDUINO_RUNNING_CORE);


  xTaskCreatePinnedToCore(
    TaskAnalogReadA3, "AnalogReadA3", 1024  // Stack size
    ,
    NULL, 1  // Priority
    ,
    &xSensorHandle, ARDUINO_RUNNING_CORE);



  // Now the task scheduler, which takes over control of scheduling individual tasks, is automatically started.
  vTaskSuspend(xSensorHandle);  // Stops the sensor task before it starts
}

void loop() {
  // Empty. Things are done in Tasks.
#ifdef defined(ESP32_RTOS) && defined(ESP32)
// If RTOS is used then this line is not compiled because its handled by tasks. To Test - Remove this line and see if it still works!
#else
  ArduinoOTA.handle();
#endif
}




/*--------------------------------------------------*/
/*---------------------- Tasks ---------------------*/
/*--------------------------------------------------*/

void TaskStateMachine(void *pvParamters) {
  (void)pvParamters;  // No Idea what this does why does it here?
  for (;;) {
    if (autoDelay.secondsDelay(2)) {           // Testing Task Control Methods
      if (eTaskGetState(xBlinkHandle) == 2) {  // enum returned:(0 eReady,1 eRunning,2 eBlocked,3 eSuspended,4 eDeleted)
        vTaskSuspend(xBlinkHandle);
      } else {
        vTaskResume(xBlinkHandle);
      }
    }
  }
}




void TaskLEDcontrol(void *pvParameters) {
  (void)pvParameters;
  for (;;) {
    Serial.print("LED TASK");
    vTaskDelay(10000);  // one tick delay (15ms) in between reads for stability
  }
}

void TaskBlink(void *pvParameters)  // This is a task.
{
  (void)pvParameters;

  /*
    Blink
    Turns on an LED on for one second, then off for one second, repeatedly.

    If you want to know what pin the on-board LED is connected to on your ESP32 model, check
    the Technical Specs of your board.
  */

  // initialize digital LED_BUILTIN on pin 13 as an output.
  pinMode(LED_BUILTIN, OUTPUT);

  for (;;)  // A Task shall never return or exit.
  {
    digitalWrite(LED_BUILTIN, HIGH);  // turn the LED on (HIGH is the voltage level)
    vTaskDelay(50);                   // one tick delay (15ms) in between reads for stability
    digitalWrite(LED_BUILTIN, LOW);   // turn the LED off by making the voltage LOW
    vTaskDelay(70);                   // one tick delay (15ms) in between reads for stability
  }
}



void TaskAnalogReadA3(void *pvParameters)  // This is a task.
{
  (void)pvParameters;

  /*
    AnalogReadSerial
    Reads an analog input on pin A3, prints the result to the serial monitor.
    Graphical representation is available using serial plotter (Tools > Serial Plotter menu)
    Attach the center pin of a potentiometer to pin A3, and the outside pins to +5V and ground.

    This example code is in the public domain.
  */

  for (;;) {
    // read the input on analog pin A3:
    int sensorValueA3 = analogRead(A3);
    // print out the value you read:
    Serial.println(sensorValueA3);
    vTaskDelay(10);  // one tick delay (15ms) in between reads for stability
  }
}

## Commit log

2023-02-16 finished front design V1, next do circuit
2023-02-17 Lots of Developments
    [A_usb_interface.kicad_sch, ISOpower_ESP32.kicad_sch, ImogenWren.kicad_sch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]
2023-02-18 nvbghnv bn
    [ws2812b-led-string.kicad_sch]
2023-03-10 Got to Routing. Keeps crashing on me
    [ISOpower_ESP32.kicad_sch, ImogenWren.kicad_sch, ws2812b-led-string.kicad_sch]
2023-03-11 Started routing board but keeps crashing
2023-03-14 Updated Schematic for Battery Charge Sense + read datasheet for battery charger IC
    [ISOpower_ESP32.kicad_sch, ImogenWren.kicad_sch]
2023-03-18 finished design V1
    [ImogenWren-B_Cu.gbr, ImogenWren-B_Mask.gbr, ImogenWren-B_Paste.gbr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]
2023-03-19 V1.1 Design Finished
    [ImogenWren-B_Cu.gbr, ImogenWren-B_Mask.gbr, ImogenWren-B_Paste.gbr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]
2023-03-21 Adding BOM
    [ISOpower_ESP32.kicad_sch, ImogenWren.csv, ImogenWren.kicad_sch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]
2023-03-23 Reorganised and renamed files
    [A_usb_interface.kicad_sch, ISOpower_ESP32.kicad_sch, ImogenWren.kicad_sch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]
2023-03-23 added JLC part numbers
    [ISOpower_ESP32.kicad_sch, ImogenWren.csv, ImogenWren.kicad_sch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]
2023-03-24 Added Complete BOM
    Ready for Parts Shopping!
    [BOM-esp32-faerfly.csv, BOM-esp32-faerfly.xlsx, ISOpower_ESP32.kicad_sch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]
2023-03-24 updated BOM
    [BOM-esp32-faerfly.csv, BOM-esp32-faerfly.xlsx]
2023-04-23 Revert "drehfrtyhrtf"
    This reverts commit bbe24f7e50a287e427fac67166e0b6a4a3b8b683.
    [unicornObject-library.ino, unicornObject.h]
2023-04-23 Added very basic test for esp32-faerfly board. Confirmed working but needs pin change
2023-04-26 Fixed compilation issue
    #TODO: Slow down animation speed it is far too fast!
    [unicornObject-library.ino, unicornObject.cpp, unicornObject.h]
2023-04-27 added 3D CAD for case design
    [COMPOUND.ipt, PCB.ipt, SOLID.ipt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]
2023-04-27 Added 3D case designs
    [V1.0-battery-holder-A.0001.ipt, V1.0-battery-holder-A.ipt, V1.0-battery-holder-A.stl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]
2023-04-27 3D cad stuff
    [V1.0-battery-holder-A.0001.ipt, V1.0-battery-holder-A.0002.ipt, V1.0-battery-holder-A.ipt]
2023-04-28 3D CAD changed to version 2, version 1 accidently overwritten in process
    [V1.2-B-faerfly-case-topside.stl, V1.3-case-topside-A.stl, V1.3-case-topside-A.stp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]
2023-04-28 added battery holder
    [v1.0-B-battery-holder.0004.ipt, v1.0-B-battery-holder.0005.ipt, v1.0-B-battery-holder.ipt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]
2023-04-29 Organised 3D cad folder
    Version B is latest version of case - hopefully last but still printing
    [V1.0-battery-holder-A.stl, V2.0-case-outer-cover-VB.0004.ipt, V2.0-case-outer-cover-VB.ipt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]
2023-04-29 Added working demo firmware. unicornObject library is considered unstable
    [faerfly-demo.ino, unicornObject.cpp, unicornObject.h]
2023-05-03 maybe be ready to roll this one back
    trying to upload to ESP32 seems to have bricked device :(
2023-05-08 Started working on V2.0 PCB
    [A_usb_interface.kicad_sch, ISOpower_ESP32.kicad_sch, MCU.kicad_sch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]
2023-05-08 started adding modifcations for V2 see changelog
    [ISOpower_ESP32.kicad_sch, USB-C.kicad_sch, ch340_ESP32.kicad_sch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]
2023-05-09 major updates to unicorn library
    - Now prints the colours picked
    - random palette picker working
    - pride palette array working.
    - Understand a little more about how the passed values play together to change the effect
    - added description for the different timing parts.
2023-05-11 major firmware update. Now introduced effects to unicorn library
    effects change how palettes are applied to LEDs
2023-05-16 Updates to V2.0 PCB
    [ISOpower_ESP32.kicad_sch, esp32-faerfly-V2.0.kicad_sch]
2023-06-08 added i2c mic test firmware
2025-01-22 update to new version
    [ISOpower_ESP32.kicad_sch, USB-C.kicad_sch, buttons.kicad_sch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]
